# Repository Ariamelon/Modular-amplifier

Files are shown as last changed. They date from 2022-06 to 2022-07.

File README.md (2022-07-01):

# Modular amplifier
A PCB for a compact but complete headphone amplifier package. Designed to fit in [this](https://item.taobao.com/item.htm?id=629378026025) case.

## Key Features
* Swappable amplifier and relay attenuator modules
* Large heatsink with variable position based on thermal planes of amplifier modules
* +-13.7V voltage rails for the amplifier modules
* +5V secondary rail for the microcontroller, relays and logic
* Power on/off anti-thump functionality
* DC offset and overheat protection
* Differential/SE mode
* Mute mode
* Standby mode

An on-board ATtiny2313A-P is used to control these functions:
* 4-channel 256-step relay-based attenuator controlled via a standard pot
* RGB state indicator LED (because why not)

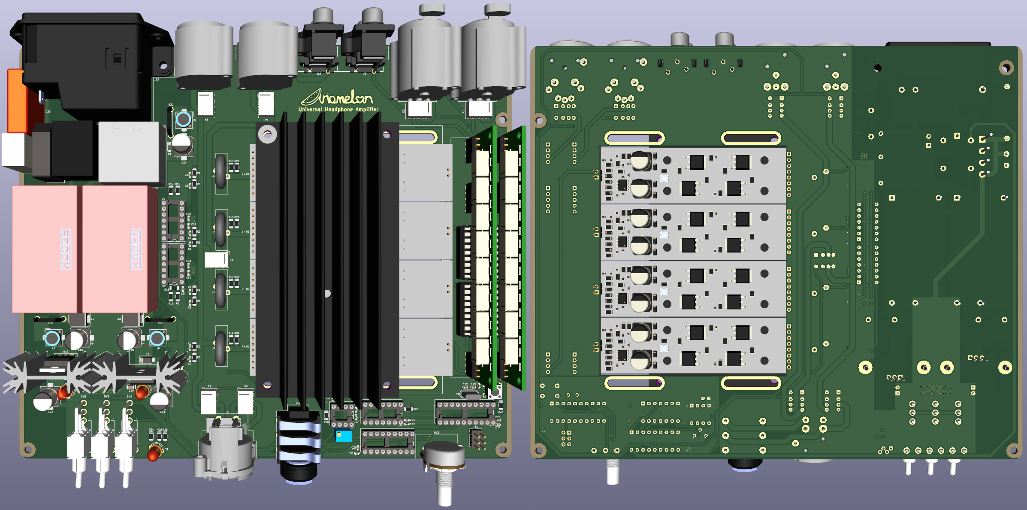
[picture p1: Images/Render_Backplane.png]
Render_Backplane

[PCB_Backplane](Images/Backplane-Assembly.pdf)
Schematic_Backplane

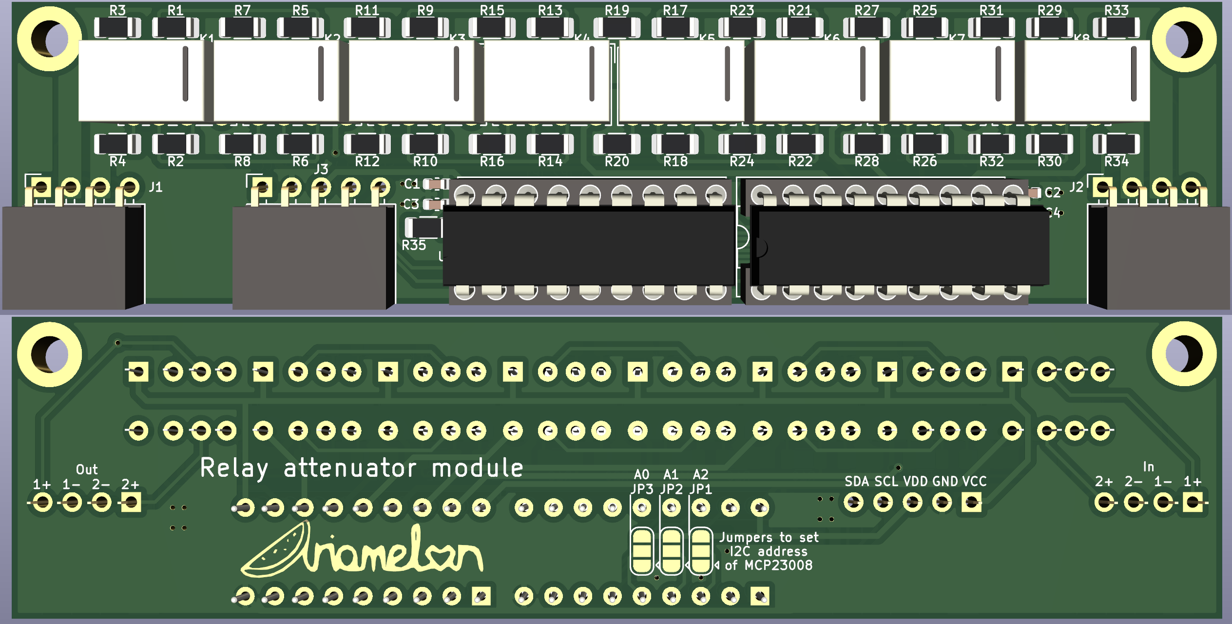
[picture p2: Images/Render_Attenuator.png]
Render_Attenuator

[PCB_Attenuator](Images/Attenuator-Assembly.pdf) 
Schematic_Attenuator

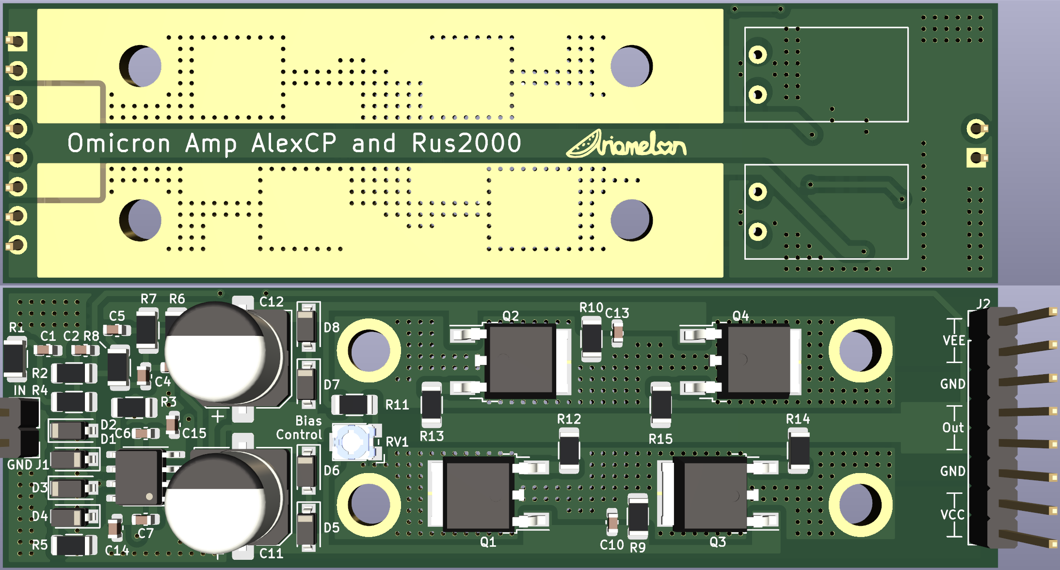
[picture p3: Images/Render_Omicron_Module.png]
Render_Omicron_Module

[PCB_Omicron_Module](Images/Omicron_Module-Assembly.pdf)
Schematic_Omicron_Module

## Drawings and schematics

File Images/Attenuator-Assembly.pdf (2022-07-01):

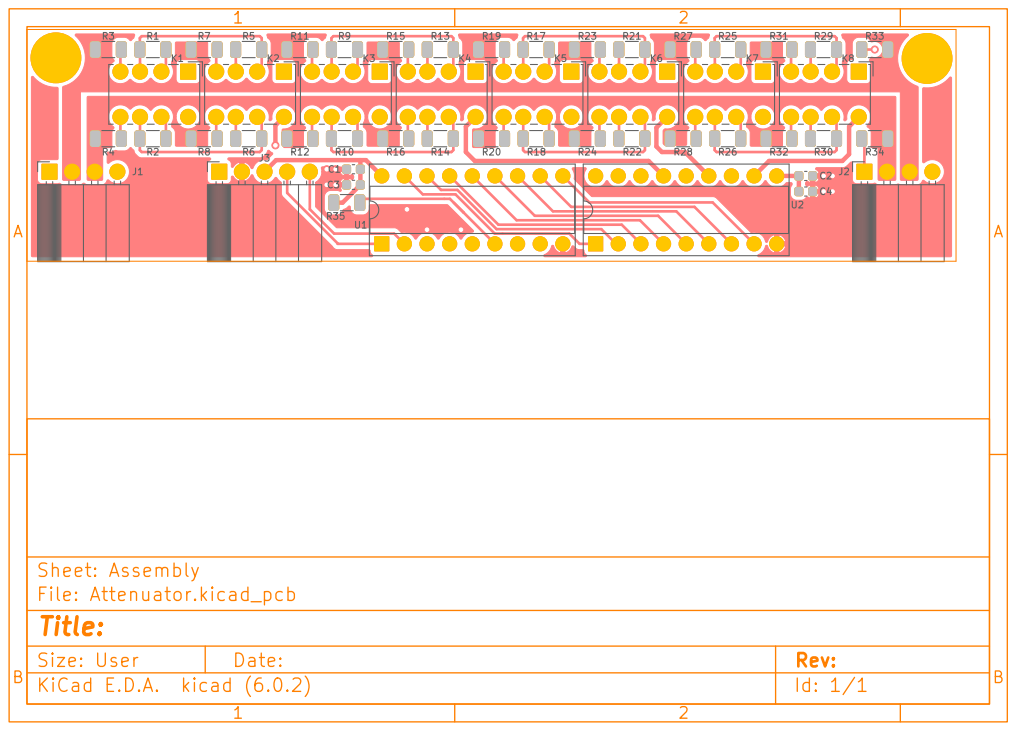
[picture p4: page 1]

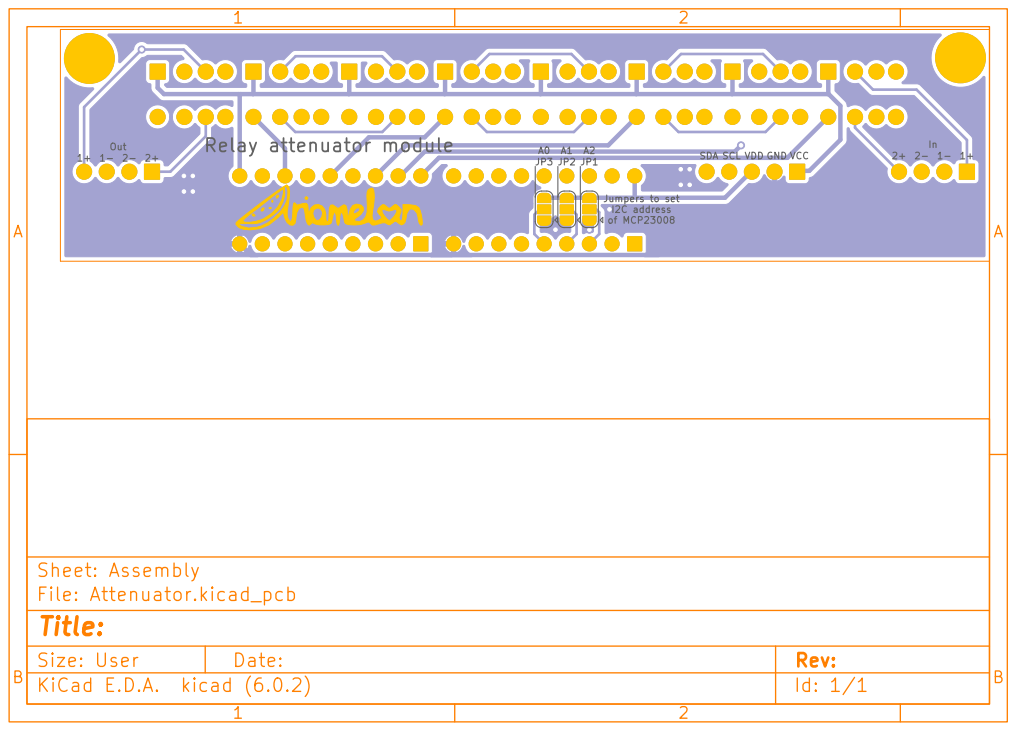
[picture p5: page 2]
In VDD; 2+ Out 1+; VCC A1; 1+ Relay attenuator module; SCL; GND; I2C address of MCP23008 A0; SDA; B Date: KiCad E.D.A. kicad (6.0.2) Size: User; Rev:; Id: 1/1 Title:; File: Attenuator.kicad_pcb; Sheet: Assembly

Jumpers to set

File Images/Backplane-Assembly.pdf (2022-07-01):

# U11 K²

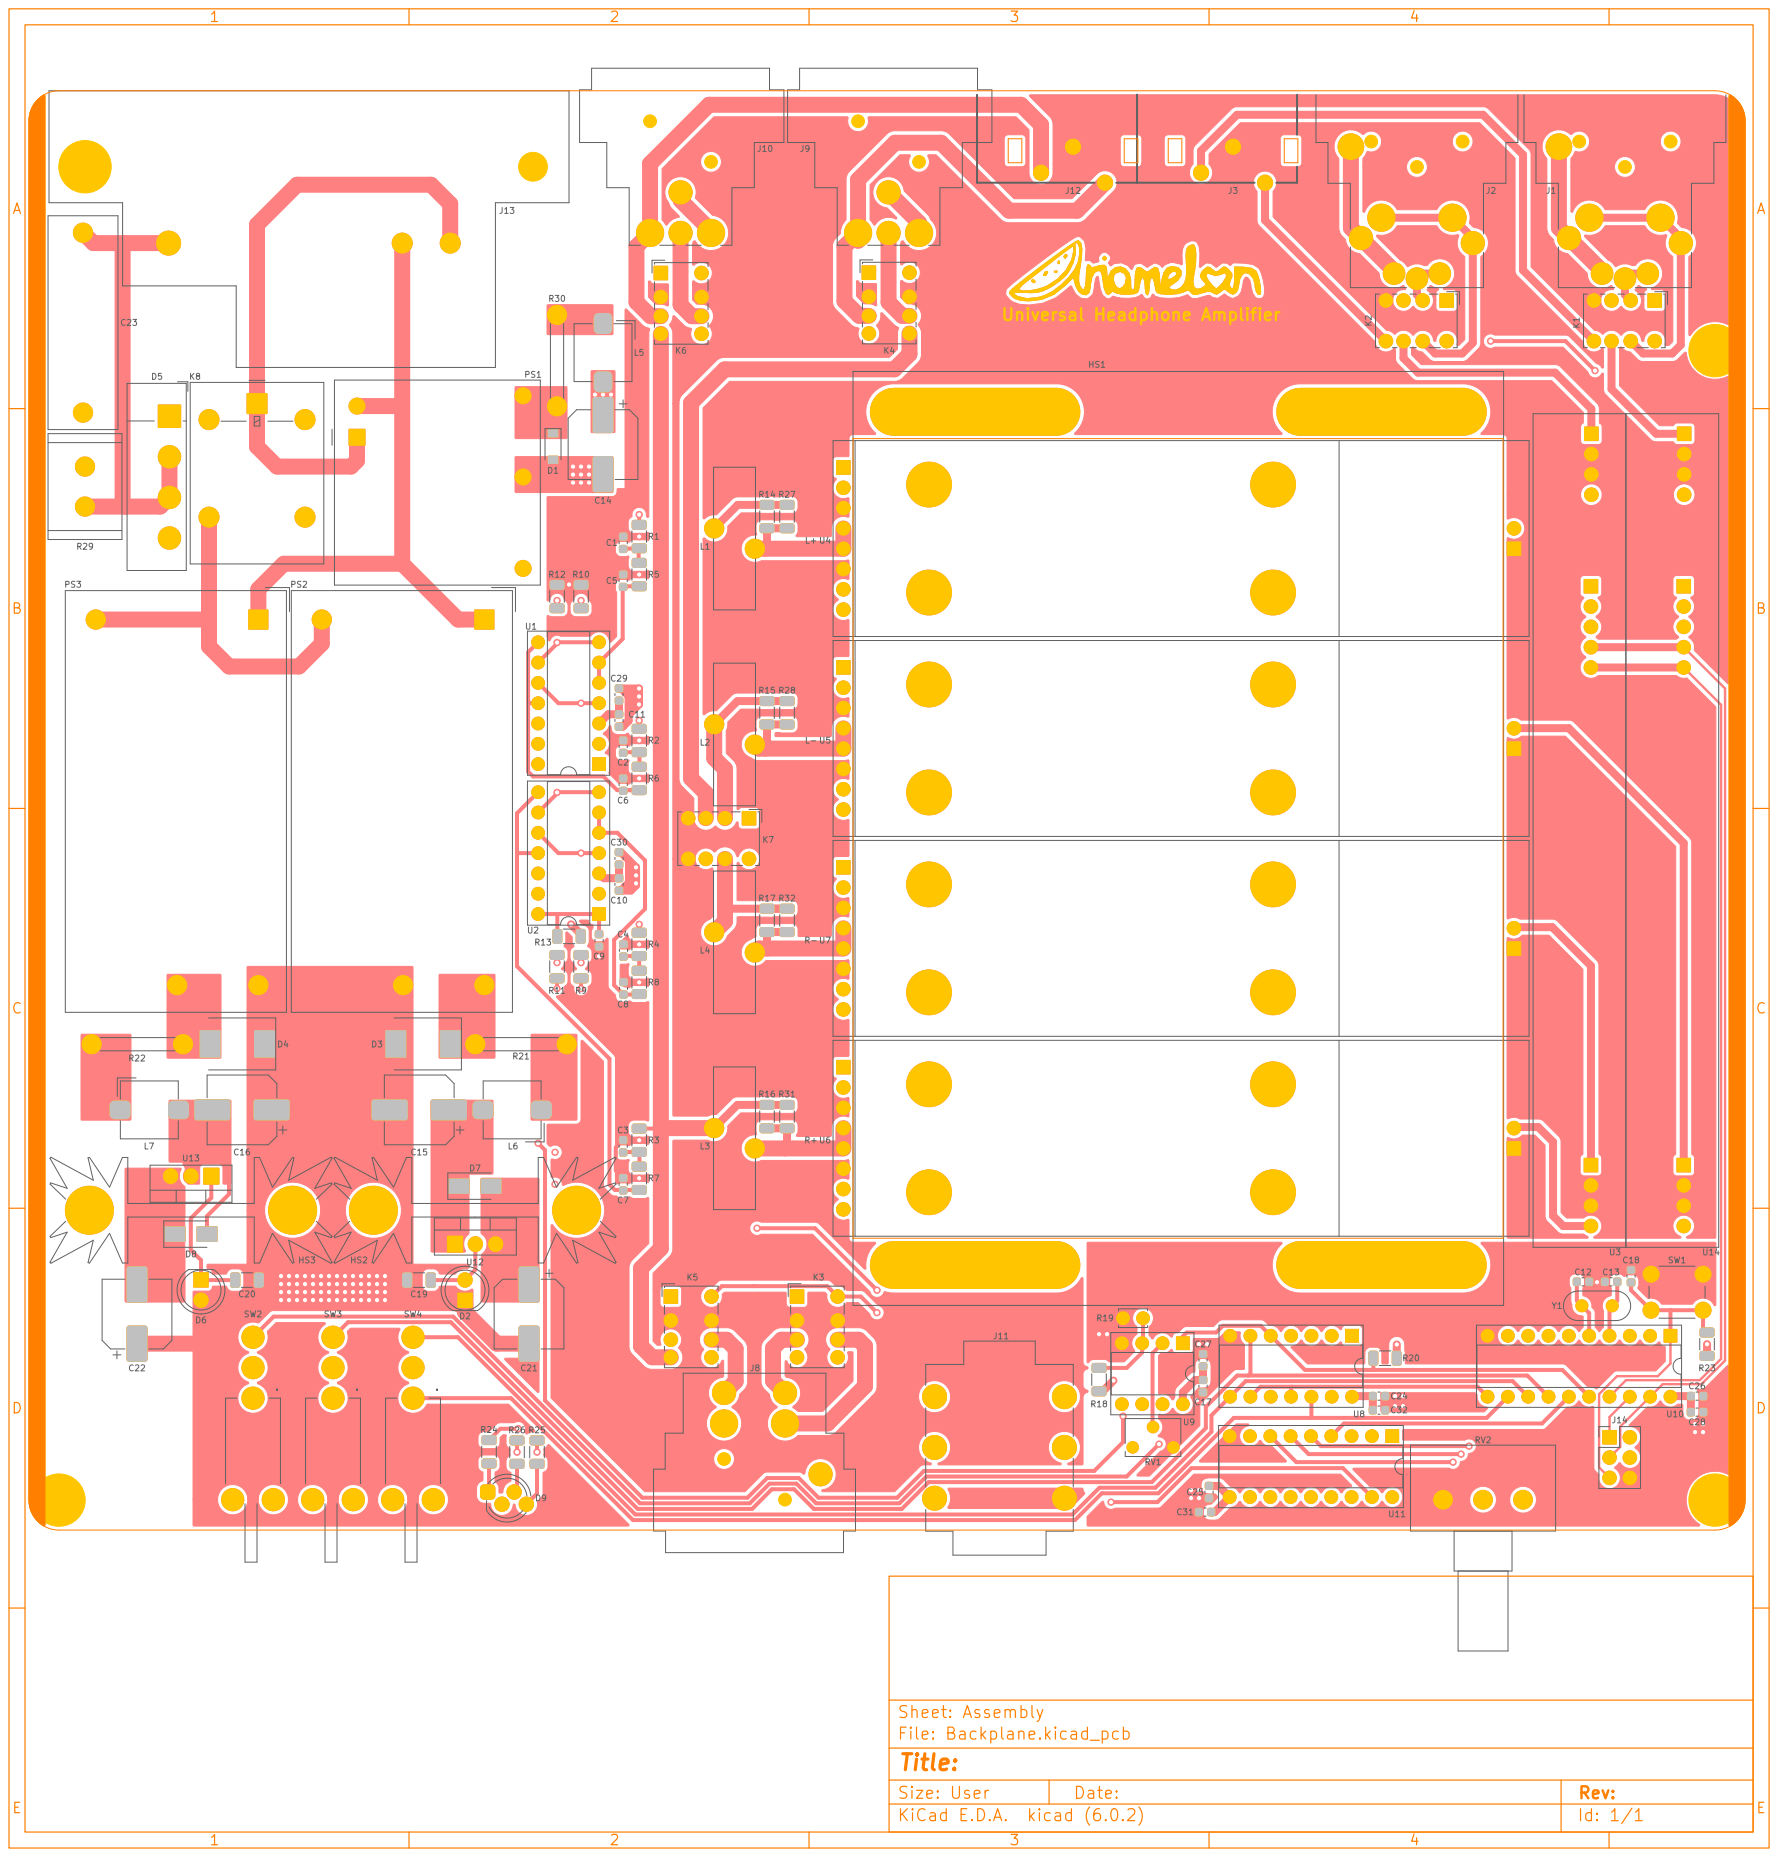
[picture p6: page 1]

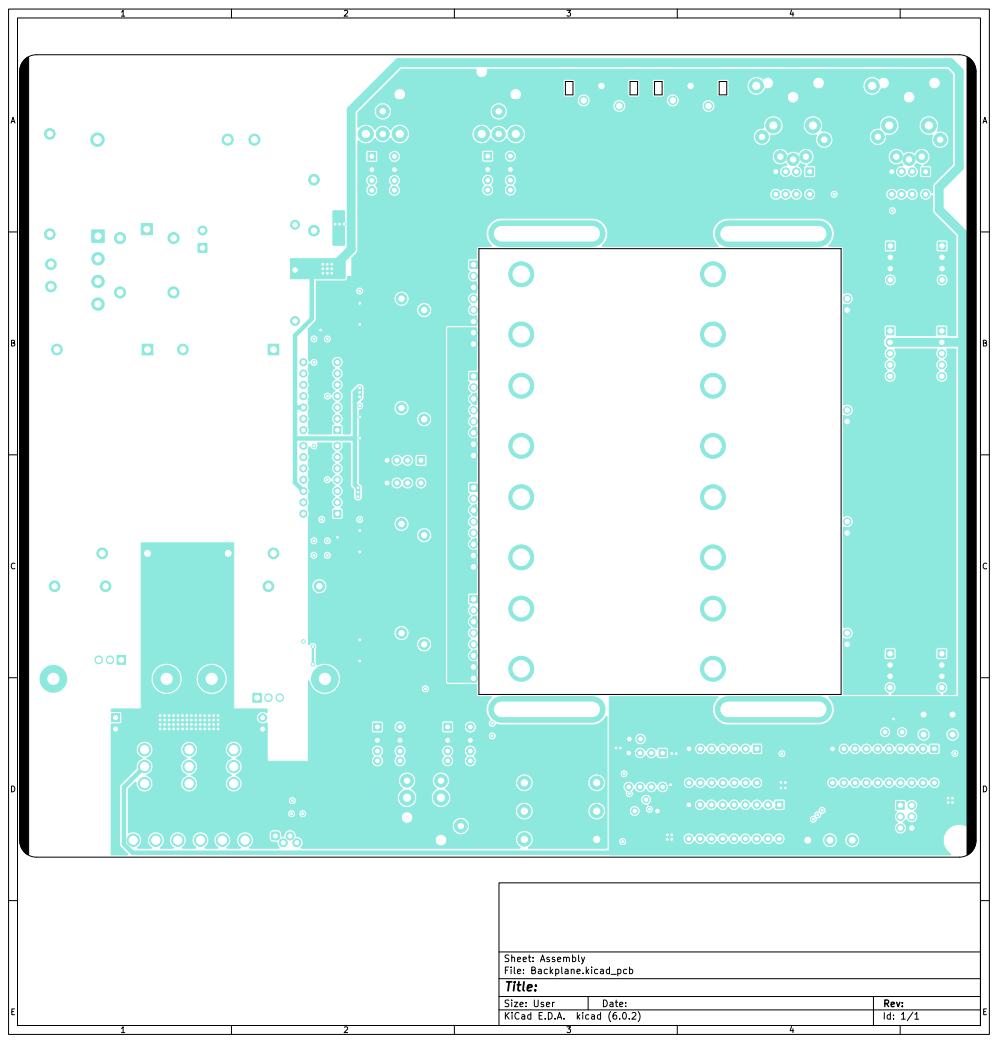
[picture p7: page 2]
File: Backplane.kicad_pcb; Sheet: Assembly

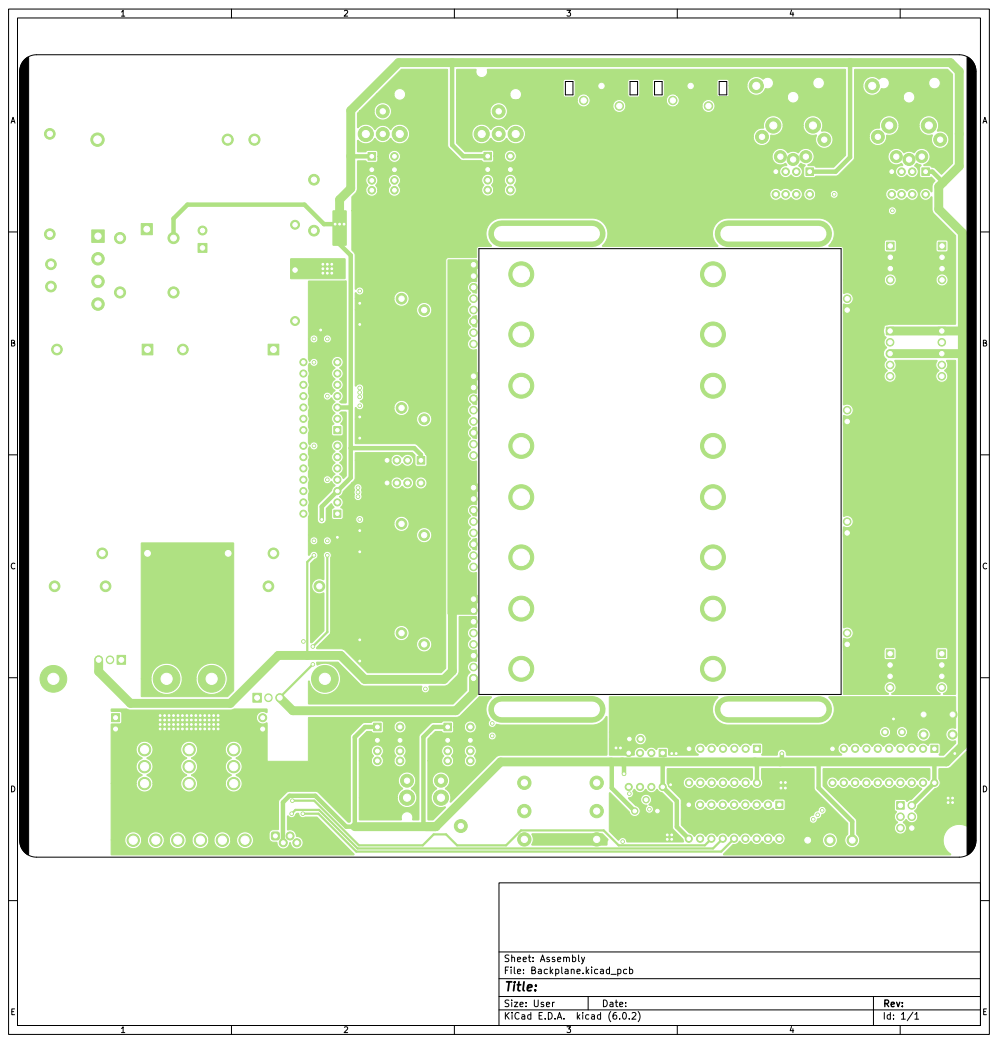
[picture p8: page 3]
File: Backplane.kicad_pcb; Sheet: Assembly

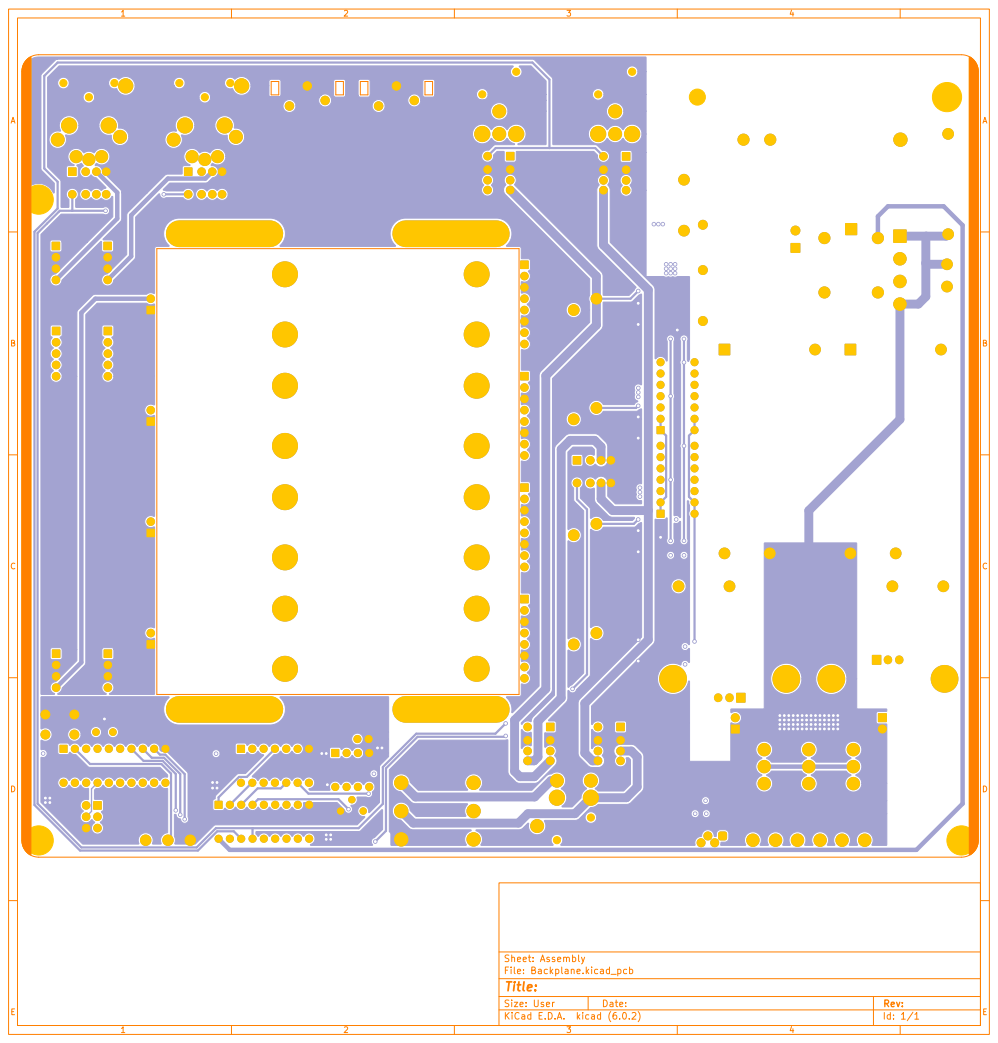
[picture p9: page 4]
File: Backplane.kicad_pcb; Sheet: Assembly

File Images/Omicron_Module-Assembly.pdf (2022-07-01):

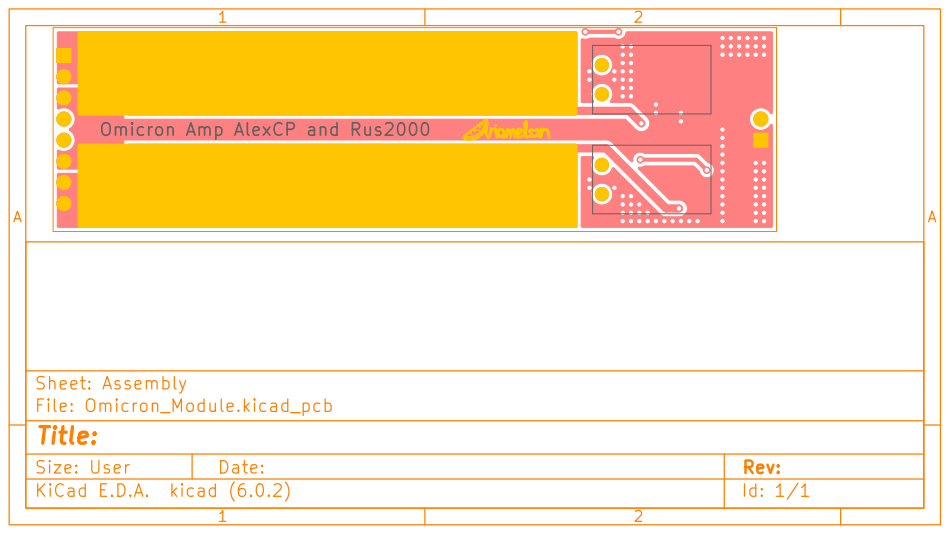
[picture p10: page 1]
A Date: KiCad E.D.A. kicad (6.0.2) Size: User; Rev:; Id: 1/1 Title:; File: Omicron_Module.kicad_pcb; Sheet: Assembly

Omicron Amp AlexCP and Rus2000

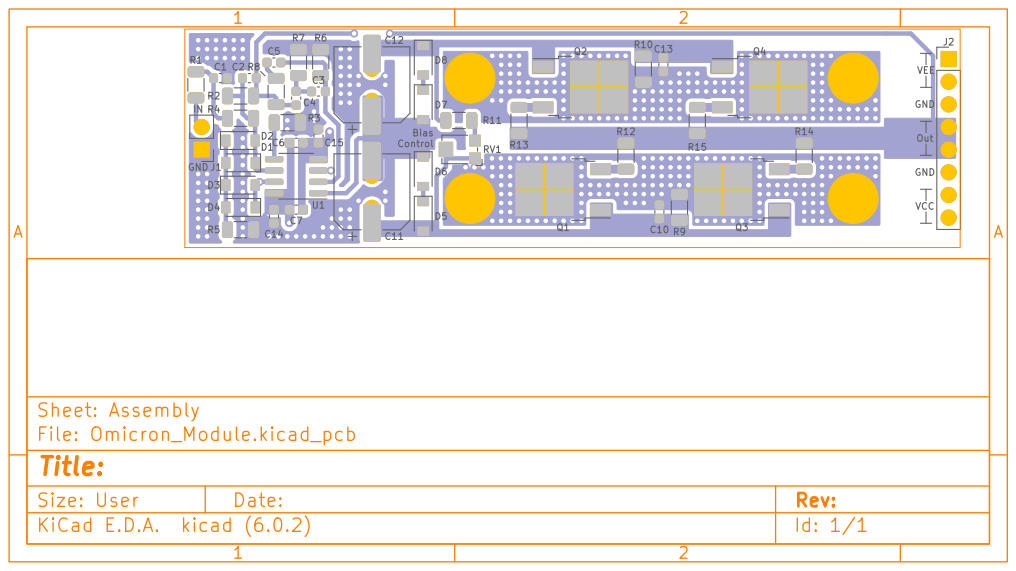
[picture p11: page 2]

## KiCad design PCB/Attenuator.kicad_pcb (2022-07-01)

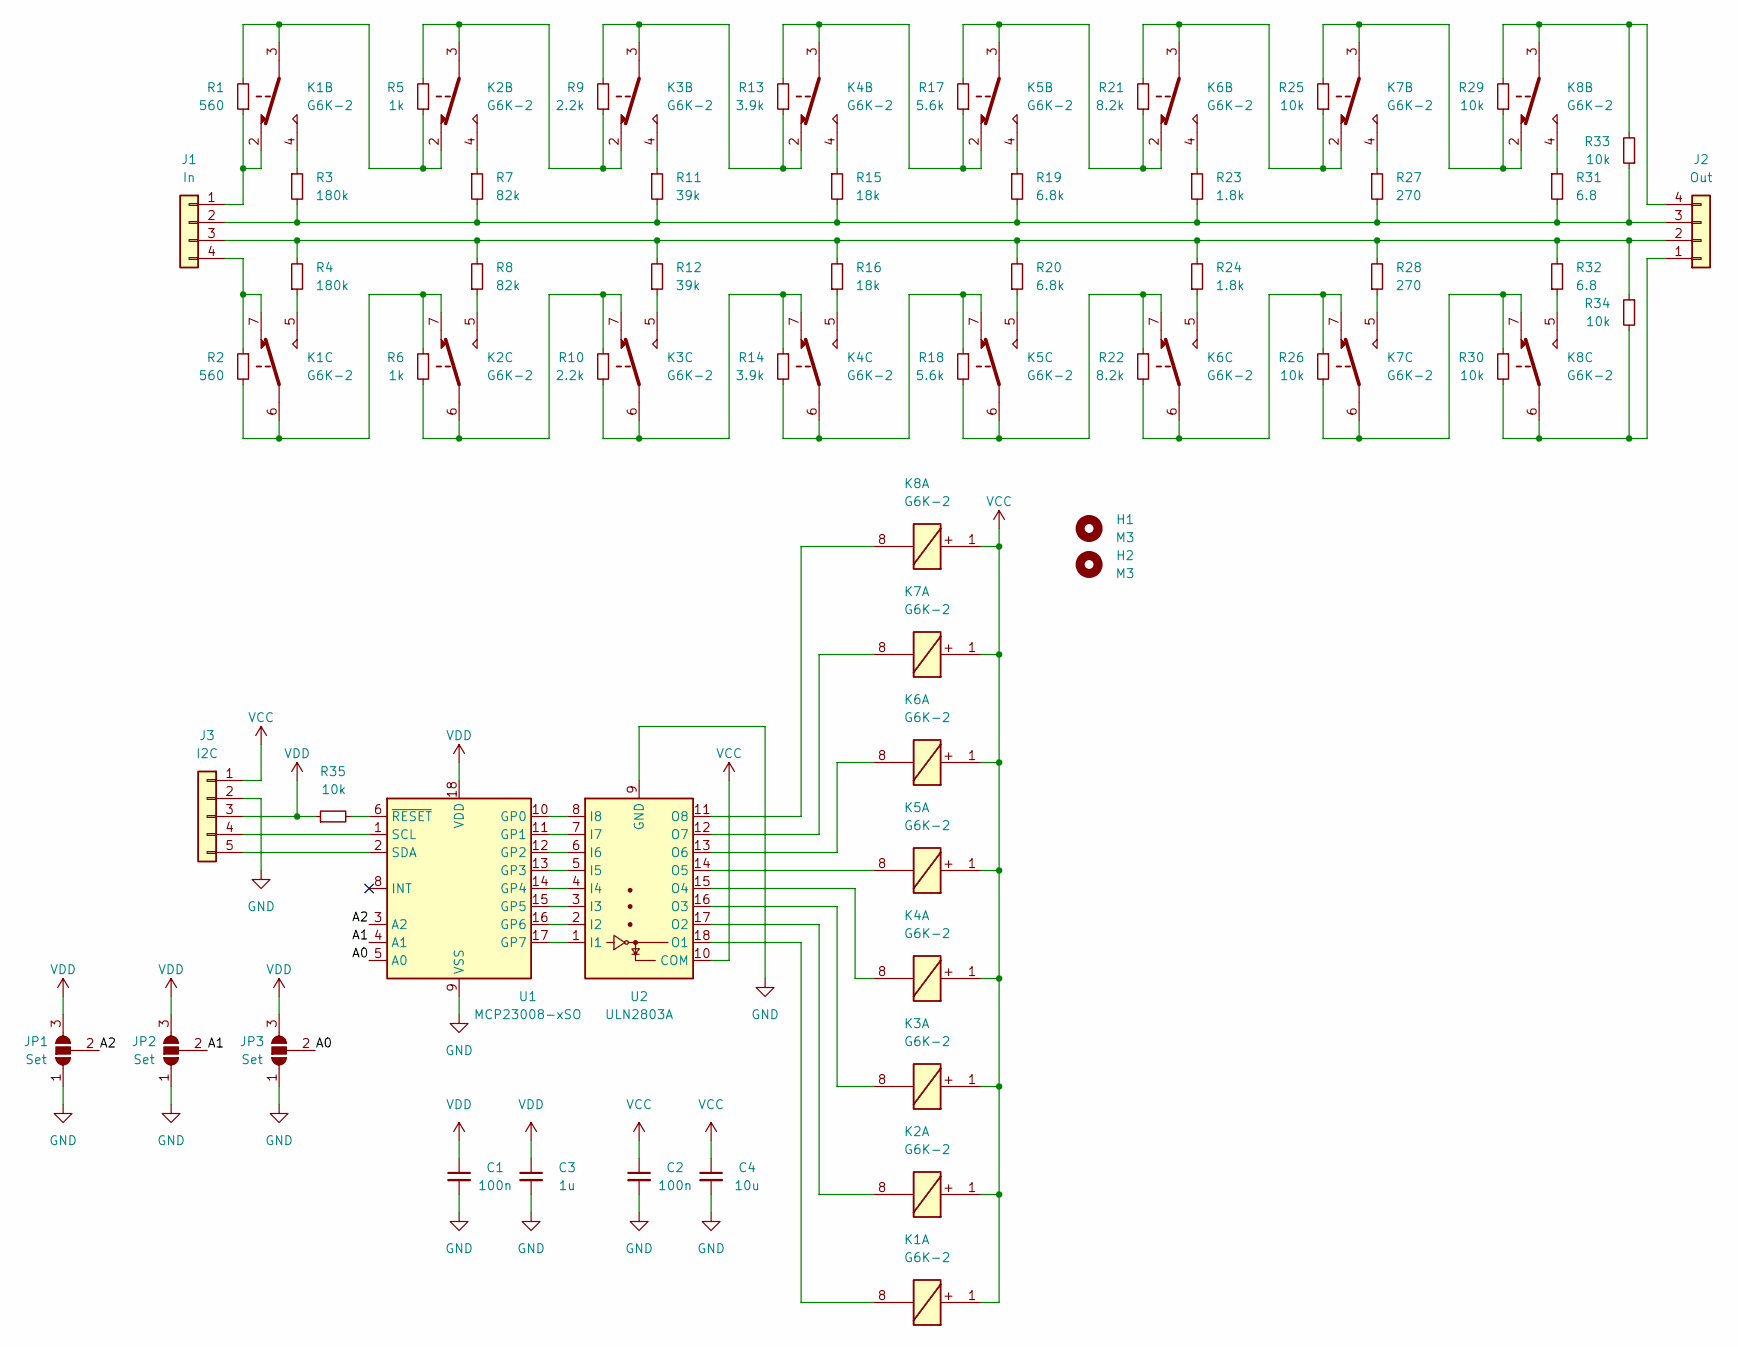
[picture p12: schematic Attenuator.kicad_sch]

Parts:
C1, C2: 100n; C_0603_1608Metric; Part number CL10A105KB8NNNC; LCSC part number C15849
C3: 1u; C_0603_1608Metric; Part number CL10A105KB8NNNC; LCSC part number C15849
C4: 10u; C_0603_1608Metric; Part number CL10A105KB8NNNC; LCSC part number C15849
H1, H2: M3; MountingHole_3.2mm_M3_DIN965_Pad
J1: In; PinSocket_1x04_P2.54mm_Horizontal
J2: Out; PinSocket_1x04_P2.54mm_Horizontal
J3: I2C; PinSocket_1x05_P2.54mm_Horizontal
JP1, JP2, JP3: Set; SolderJumper-3_P1.3mm_Open_RoundedPad1.0x1.5mm
K1, K2, K3, K4, K5, K6, K7, K8: G6K-2; Relay_DPDT_Omron_G6K-2P-Y
R1, R2: 560; R_1206_3216Metric
R3, R4: 180k; R_1206_3216Metric
R5, R6: 1k; R_1206_3216Metric
R7, R8: 82k; R_1206_3216Metric
R9, R10: 2.2k; R_1206_3216Metric
R11, R12: 39k; R_1206_3216Metric
R13, R14: 3.9k; R_1206_3216Metric
R15, R16: 18k; R_1206_3216Metric
R17, R18: 5.6k; R_1206_3216Metric
R19, R20: 6.8k; R_1206_3216Metric
R21, R22: 8.2k; R_1206_3216Metric
R23, R24: 1.8k; R_1206_3216Metric
R25, R26, R29, R30, R33, R34, R35: 10k; R_1206_3216Metric
R27, R28: 270; R_1206_3216Metric
R31, R32: 6.8; R_1206_3216Metric
U1: MCP23008-xSO; DIP-18_W7.62mm_Socket
U2: ULN2803A; DIP-18_W7.62mm_Socket

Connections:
/A0: JP3.2 (C), U1.5 (A0)
/A1: JP2.2 (C), U1.4 (A1)
/A2: JP1.2 (C), U1.3 (A2)
GND: C1.2, C2.2, C3.2, C4.2, J3.2, JP1.1 (A), JP2.1 (A), JP3.1 (A), U1.9 (VSS), U2.9 (GND)
unnamed: J1.1, K1.2, R1.1
unnamed: J1.2, J2.3, R3.2, R7.2, R11.2, R15.2, R19.2, R23.2, R27.2, R31.2, R33.1
unnamed: J1.3, J2.2, R4.2, R8.2, R12.2, R16.2, R20.2, R24.2, R28.2, R32.2, R34.1
unnamed: J1.4, K1.7, R2.1
unnamed: J2.1, K8.6, R30.2, R34.2
unnamed: J2.4, K8.3, R29.2, R33.2
unnamed: J3.4, U1.1 (SCL)
unnamed: J3.5, U1.2 (SDA)
unnamed: K1.3, K2.2, R1.2, R5.1
unnamed: K1.4, R3.1
unnamed: K1.5, R4.1
unnamed: K1.6, K2.7, R2.2, R6.1
unnamed: K1.8, U2.18 (O1)
unnamed: K2.3, K3.2, R5.2, R9.1
unnamed: K2.4, R7.1
unnamed: K2.5, R8.1
unnamed: K2.6, K3.7, R6.2, R10.1
unnamed: K2.8, U2.17 (O2)
unnamed: K3.3, K4.2, R9.2, R13.1
unnamed: K3.4, R11.1
unnamed: K3.5, R12.1
unnamed: K3.6, K4.7, R10.2, R14.1
unnamed: K3.8, U2.16 (O3)
unnamed: K4.3, K5.2, R13.2, R17.1
unnamed: K4.4, R15.1
unnamed: K4.5, R16.1
unnamed: K4.6, K5.7, R14.2, R18.1
unnamed: K4.8, U2.15 (O4)
unnamed: K5.3, K6.2, R17.2, R21.1
unnamed: K5.4, R19.1
unnamed: K5.5, R20.1
unnamed: K5.6, K6.7, R18.2, R22.1
unnamed: K5.8, U2.14 (O5)
unnamed: K6.3, K7.2, R21.2, R25.1
unnamed: K6.4, R23.1
unnamed: K6.5, R24.1
unnamed: K6.6, K7.7, R22.2, R26.1
unnamed: K6.8, U2.13 (O6)
unnamed: K7.3, K8.2, R25.2, R29.1
unnamed: K7.4, R27.1
unnamed: K7.5, R28.1
unnamed: K7.6, K8.7, R26.2, R30.1
unnamed: K7.8, U2.12 (O7)
unnamed: K8.4, R31.1
unnamed: K8.5, R32.1
unnamed: K8.8, U2.11 (O8)
unnamed: R35.2, U1.6 (~RESET)
unnamed: U1.10 (GP0), U2.8 (I8)
unnamed: U1.11 (GP1), U2.7 (I7)
unnamed: U1.12 (GP2), U2.6 (I6)
unnamed: U1.13 (GP3), U2.5 (I5)
unnamed: U1.14 (GP4), U2.4 (I4)
unnamed: U1.15 (GP5), U2.3 (I3)
unnamed: U1.16 (GP6), U2.2 (I2)
unnamed: U1.17 (GP7), U2.1 (I1)
VCC: C2.1, C4.1, J3.1, K1.1, K2.1, K3.1, K4.1, K5.1, K6.1, K7.1, K8.1, U2.10 (COM)
VDD: C1.1, C3.1, J3.3, JP1.3 (B), JP2.3 (B), JP3.3 (B), R35.1, U1.18 (VDD)

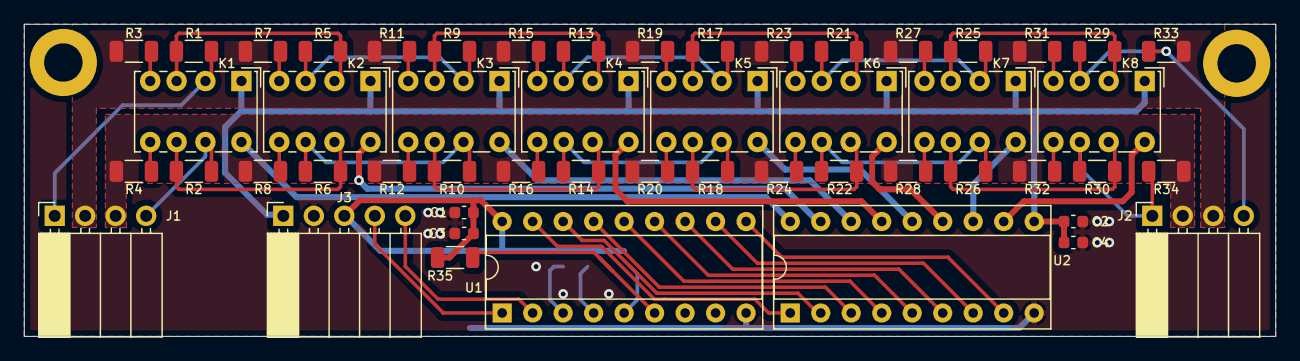
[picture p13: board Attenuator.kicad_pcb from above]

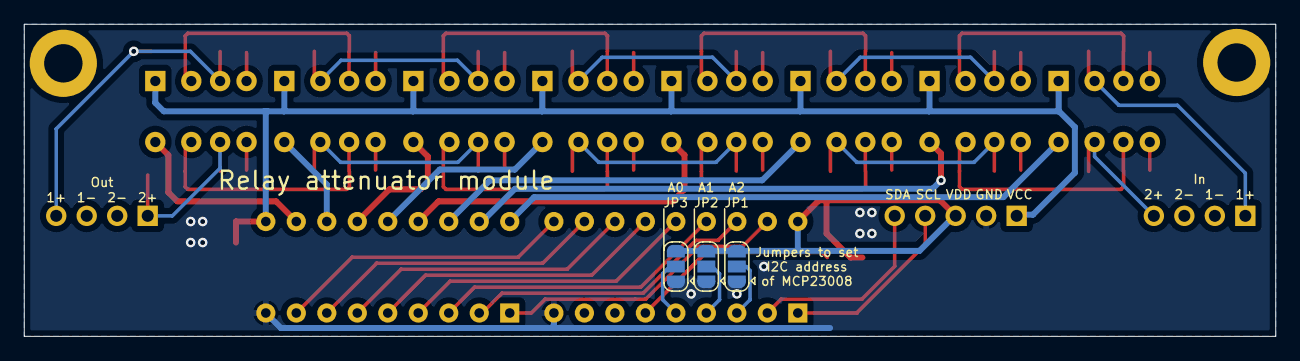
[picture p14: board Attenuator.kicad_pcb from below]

Board: 2 copper layers, 104.2 x 26.0 mm, 57 parts (3 on the bottom side), 61 nets.

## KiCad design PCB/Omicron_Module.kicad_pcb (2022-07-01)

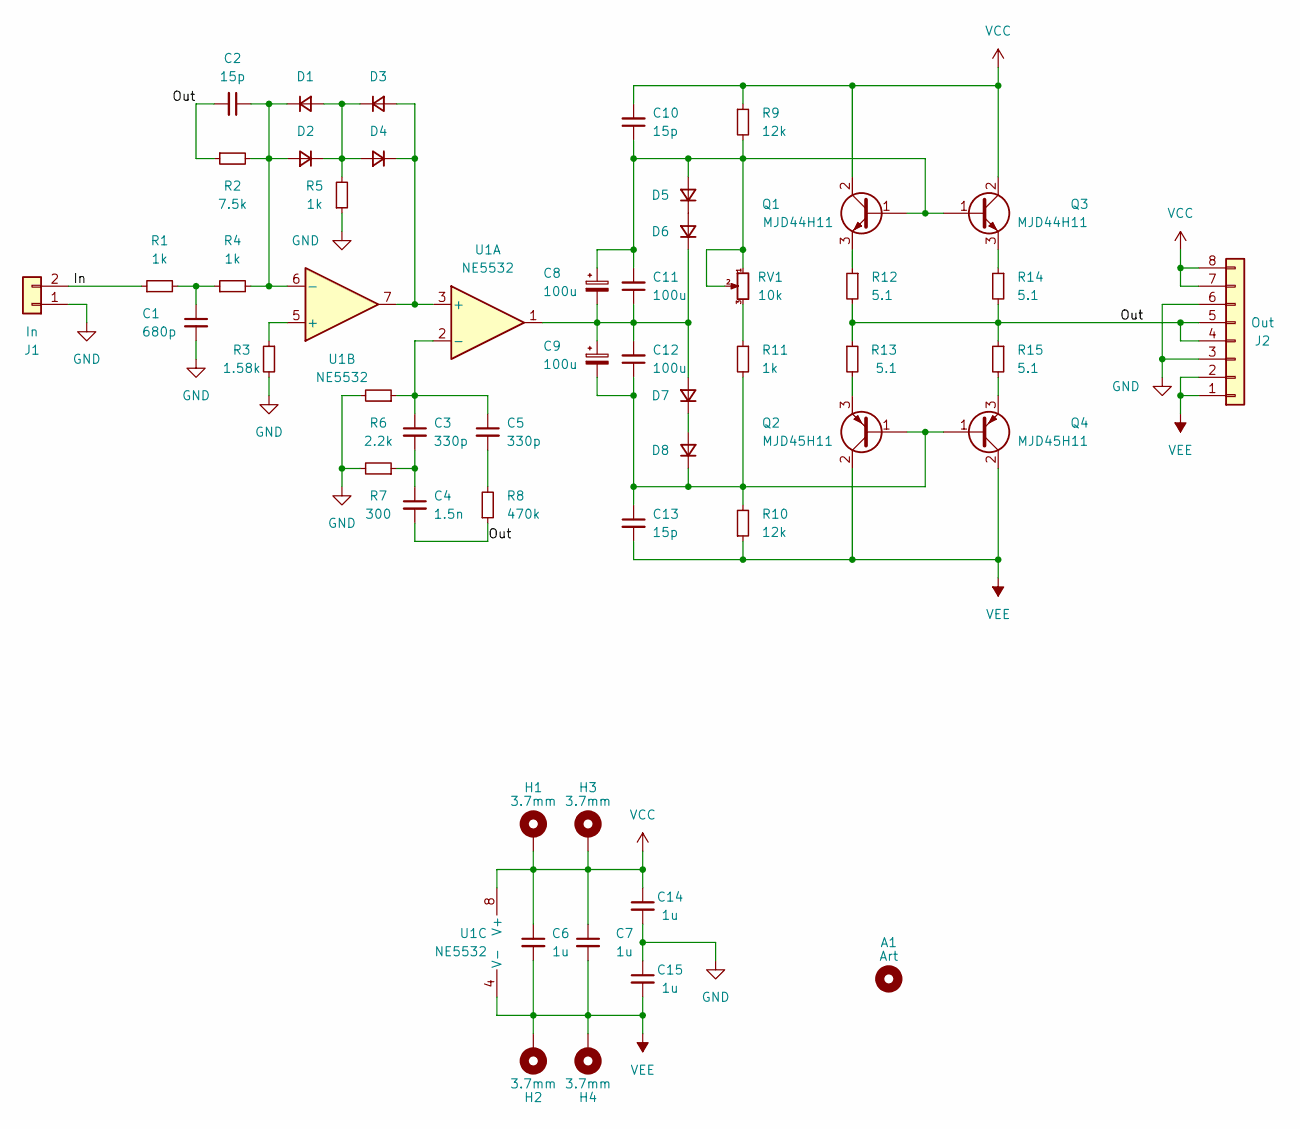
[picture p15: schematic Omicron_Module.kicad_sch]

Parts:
A1: Art; Ariamelon_Logo_CU
C1: 680p; C_0603_1608Metric
C2, C10, C13: 15p; C_0603_1608Metric
C3, C5: 330p; C_0603_1608Metric
C4: 1.5n; C_0603_1608Metric
C6, C7, C14, C15: 1u; C_0603_1608Metric; Part number CL10A105KB8NNNC; LCSC part number C15849
C8, C9: 100u; CP_Elec_8x6.9; Part number EEE-FK1V101GV
C11, C12: 100u; C_Radial_D8.0mm_H11.5mm_P3.50mm_Sideways; Part number EEE-FK1V101GV
D1, D2, D3, D4, D5, D6, D7, D8: D; D_SOD-123; Part number 1N4148W; LCSC part number C81598
H1, H2, H3, H4: 3.7mm; MountingHole_3.2mm_M3_DIN965_Pad_3.7mm_Hole
J1: In; PinHeader_1x02_P2.54mm_Vertical
J2: Out; PinHeader_1x08_P2.54mm_Vertical
Q1, Q3: MJD44H11; TO-252-2
Q2, Q4: MJD45H11; TO-252-2
R1, R4, R5, R11: 1k; R_1206_3216Metric
R2: 7.5k; R_1206_3216Metric
R3: 1.58k; R_1206_3216Metric
R6: 2.2k; R_1206_3216Metric
R7: 300; R_1206_3216Metric
R8: 470k; R_1206_3216Metric
R9, R10: 12k; R_1206_3216Metric
R12, R13, R14, R15: 5.1; R_1206_3216Metric
RV1: 10k; Potentiometer_Bourns_TC33X_Vertical
U1: NE5532; SOIC-8_3.9x4.9mm_P1.27mm

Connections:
/In: J1.2, R1.1
/Out: C2.2, C4.2, J2.4, J2.5, R2.1, R8.1, R12.2, R13.1, R14.2, R15.1
GND: C1.2, C14.2, C15.1, J1.1, J2.3, J2.6, R3.2, R5.1, R6.2, R7.2
unnamed: C1.1, R1.2, R4.1
unnamed: C2.1, D1.1 (K), D2.2 (A), R2.2, R4.2, U1.6 (-)
unnamed: C3.1, C5.1, R6.1, U1.2 (-)
unnamed: C3.2, C4.1, R7.1
unnamed: C5.2, R8.2
unnamed: C8.1, C10.1, C11.2, D5.2 (A), Q1.1 (B), Q3.1 (B), R9.2, RV1.1, RV1.2
unnamed: C8.2, C9.1, C11.1, C12.2, D6.1 (K), D7.2 (A), U1.1
unnamed: C9.2, C12.1, C13.1, D8.1 (K), Q2.1 (B), Q4.1 (B), R10.2, R11.2
unnamed: D1.2 (A), D2.1 (K), D3.1 (K), D4.2 (A), R5.2
unnamed: D3.2 (A), D4.1 (K), U1.3 (+), U1.7
unnamed: D5.1 (K), D6.2 (A)
unnamed: D7.1 (K), D8.2 (A)
unnamed: Q1.3 (E), R12.1
unnamed: Q2.3 (E), R13.2
unnamed: Q3.3 (E), R14.1
unnamed: Q4.3 (E), R15.2
unnamed: R3.1, U1.5 (+)
unnamed: R11.1, RV1.3
VCC: C6.1, C7.1, C10.2, C14.1, H1.1, H3.1, J2.7, J2.8, Q1.2 (C), Q3.2 (C), R9.1, U1.8 (V+)
VEE: C6.2, C7.2, C13.2, C15.2, H2.1, H4.1, J2.1, J2.2, Q2.2 (C), Q4.2 (C), R10.1, U1.4 (V-)

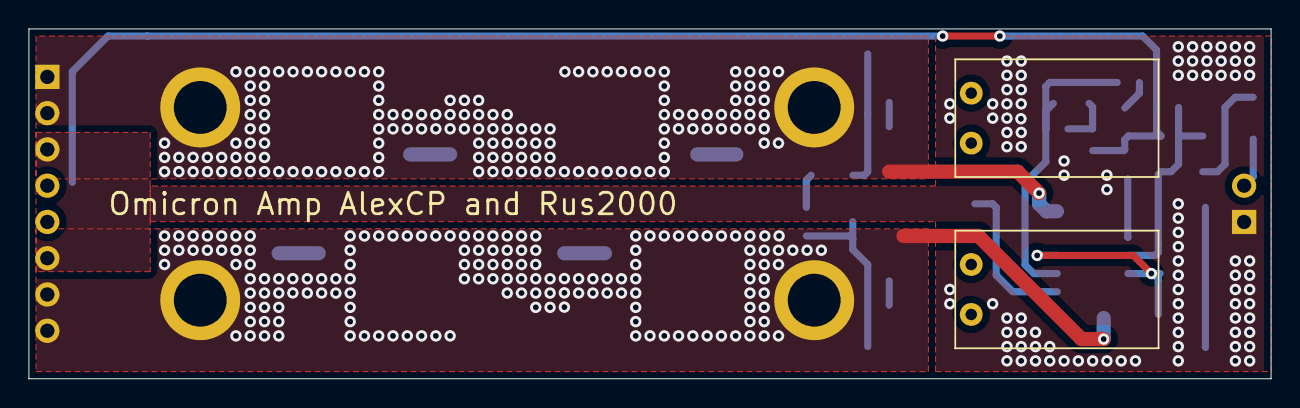
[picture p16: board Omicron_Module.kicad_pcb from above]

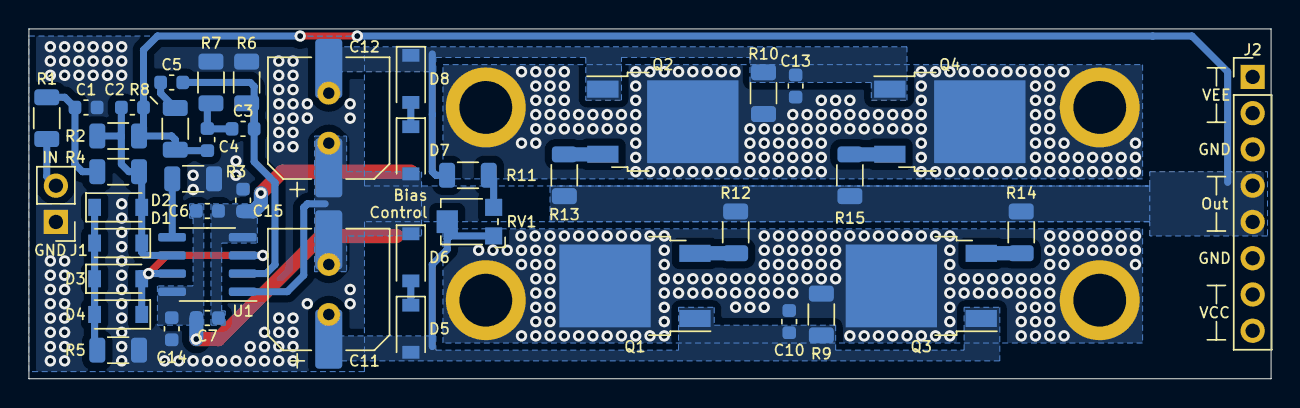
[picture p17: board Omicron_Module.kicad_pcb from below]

Board: 2 copper layers, 87.0 x 24.5 mm, 51 parts (48 on the bottom side), 23 nets.

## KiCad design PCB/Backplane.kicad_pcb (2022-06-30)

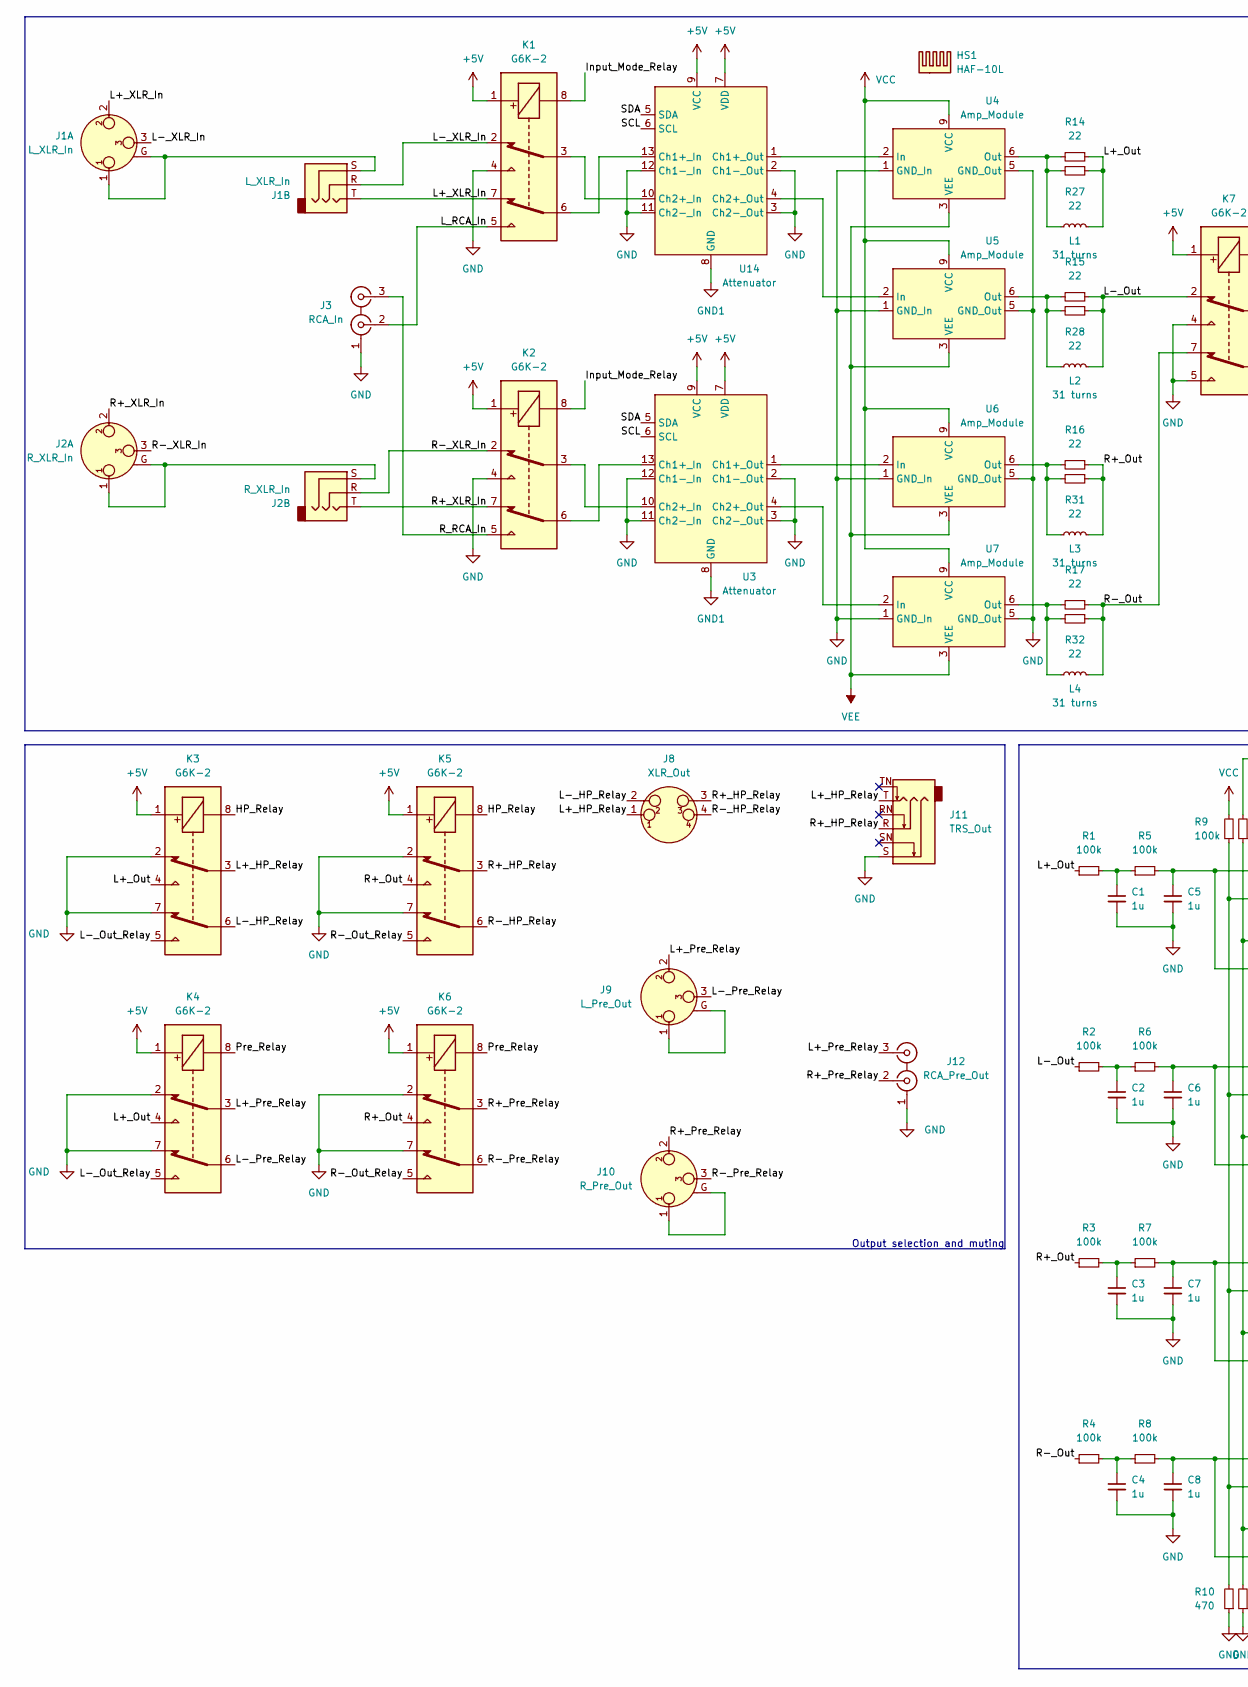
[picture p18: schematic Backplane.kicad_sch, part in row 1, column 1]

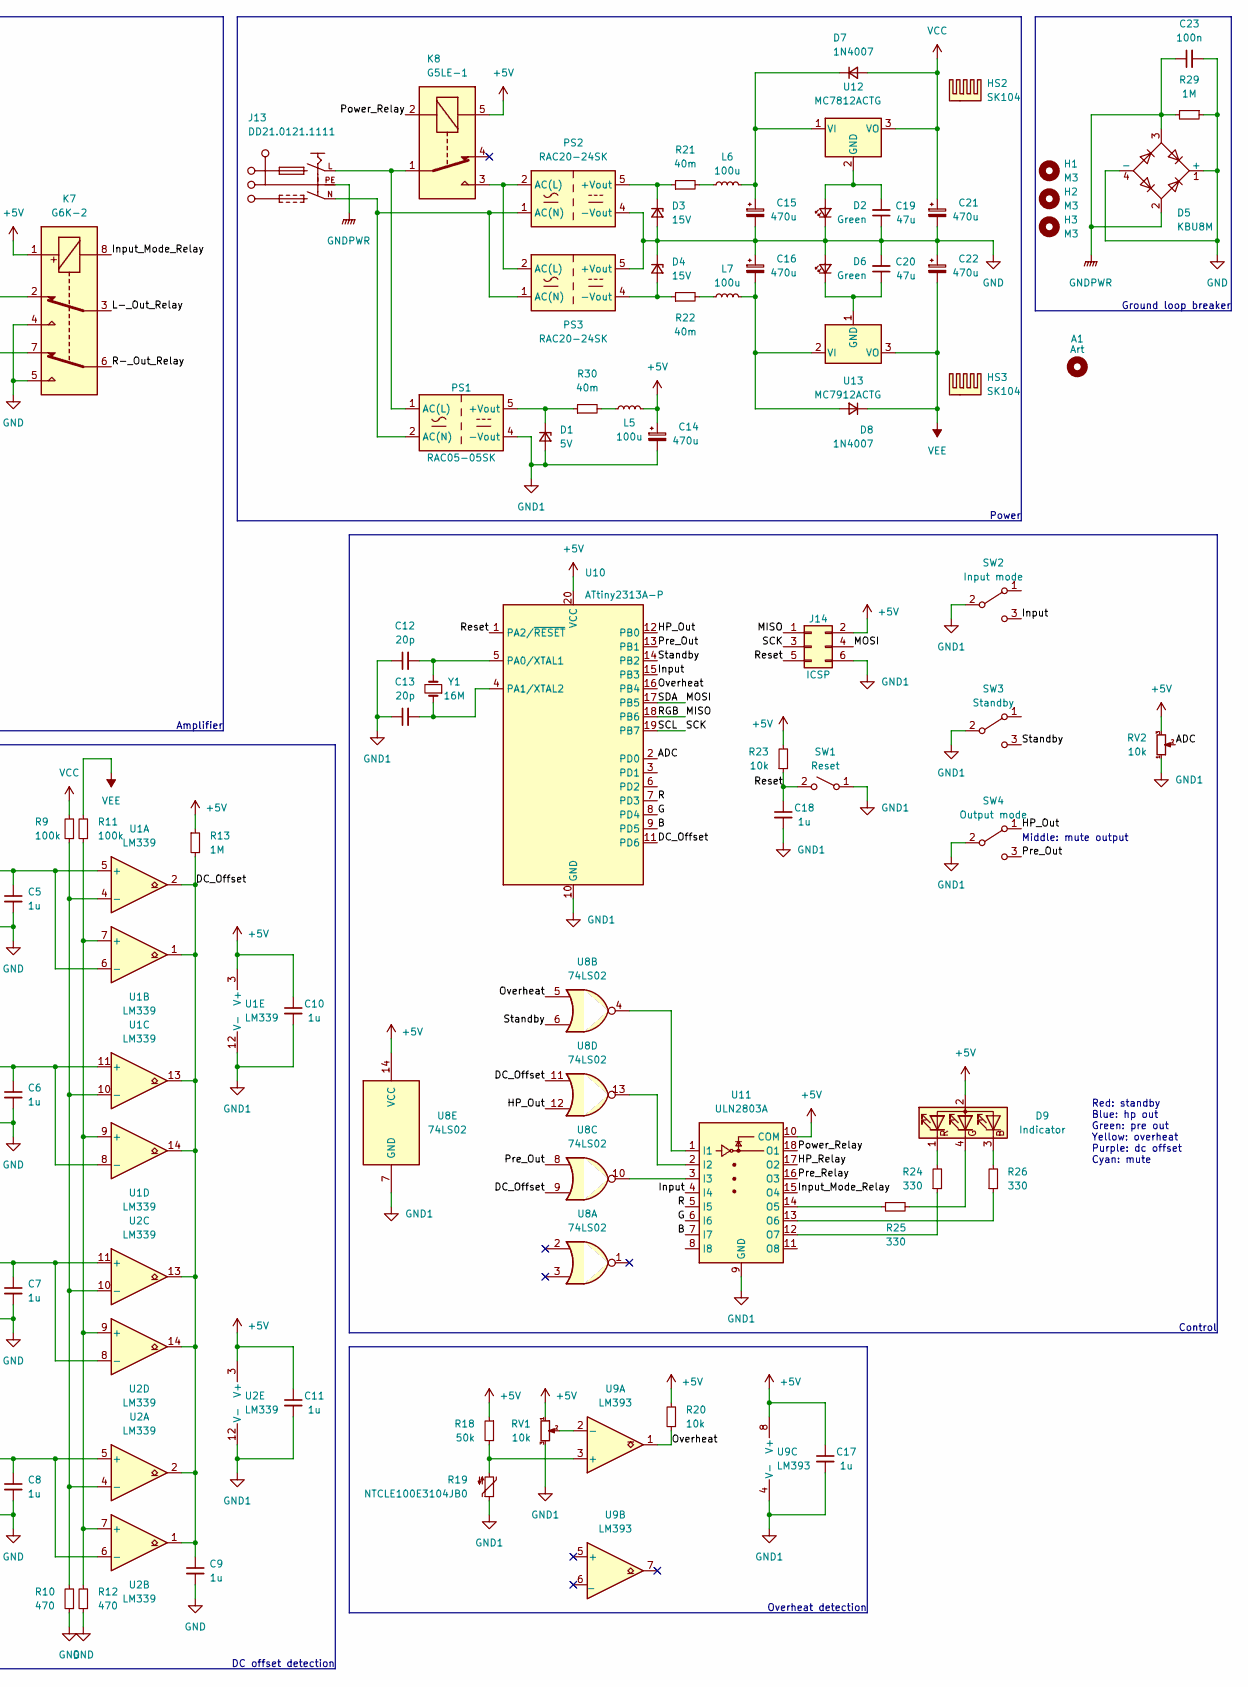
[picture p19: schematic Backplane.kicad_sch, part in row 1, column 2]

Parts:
A1: Art; Ariamelon_Logo_x3_CU
C1, C2, C3, C4, C5, C6, C7, C8: 1u; C_0603_1608Metric
C9, C10, C11, C17, C18: 1u; C_0603_1608Metric; Part number CL10A105KB8NNNC; LCSC part number C15849
C12, C13: 20p; C_0603_1608Metric
C14, C15, C16, C21, C22: 470u; CP_Elec_8x10.5; Part number EEEFT1E471GP; LCSC part number C193277
C19, C20: 47u; C_1206_3216Metric
C23: 100n; C_Rect_L26.5mm_W8.5mm_P22.50mm_MKS4; Part number PHE820ED6100MR06L2; LCSC part number C2926846
D1: 5V; D_SOD-123; LCSC part number C193402
D2, D6: Green; LED_D5.0mm
D3, D4: 15V; D_SMC; Part number SMCJ15CA-13-F
D5: KBU8M; Diode_Bridge_Vishay_KBU
D7, D8: 1N4007; D_SMA
D9: Indicator; LED_D5.0mm-4_RGB_Staggered_Pins
H1, H2, H3: M3; MountingHole_3.2mm_M3
HS1: HAF-10L
HS2, HS3: SK104; Heatsink_Fischer_SK104-STC-STIC_35x13mm_2xDrill2.5mm
J1: L_XLR_In; Jack_XLR-6.35mm_Neutrik_NCJ6FA-H_Horizontal
J2: R_XLR_In; Jack_XLR-6.35mm_Neutrik_NCJ6FA-H_Horizontal
J3: RCA_In; RCJ-2221
J8: XLR_Out; Jack_XLR_Neutrik_NC4FAH_Horizontal
J9: L_Pre_Out; Jack_XLR_Neutrik_NC3MAH_Horizontal
J10: R_Pre_Out; Jack_XLR_Neutrik_NC3MAH_Horizontal
J11: TRS_Out; Jack_6.35mm_Neutrik_NMJ6HCD2_Horizontal
J12: RCA_Pre_Out; RCJ-2221
J13: DD21.0121.1111; SCHURTER_DD21.0121.1111
J14: ICSP; PinHeader_2x03_P2.54mm_Vertical
K1, K2, K3, K4, K5, K6, K7: G6K-2; Relay_DPDT_Omron_G6K-2P-Y
K8: G5LE-1; Relay_SPDT_Omron-G5LE-1
L1, L2, L3, L4: 31 turns; L_Toroid_D15mm_W4mm; Part number N/A; LCSC part number N/A
L5, L6, L7: 100u; L_TDK_SLF7032; Part number SPM7054VT-101M-D; LCSC part number C2045491
PS1: RAC05-05SK; Converter_ACDC_RECOM_RAC05-xxSK_THT
PS2, PS3: RAC20-24SK; Converter_ACDC_Recom_RAC20-xxSK_THT
R1, R2, R3, R4, R5, R6, R7, R8, R9, R11: 100k; R_1206_3216Metric; Part number RT1206FRD0710KL; LCSC part number C705072
R10, R12: 470; R_1206_3216Metric; Part number RT1206FRD0710KL; LCSC part number C705072
R13: 1M; R_1206_3216Metric; Part number RT1206FRE071ML; LCSC part number C375528
R14, R15, R16, R17, R27, R28, R31, R32: 22; R_1206_3216Metric; Part number RT1206FRD073RL; LCSC part number C326707
R18: 50k; R_1206_3216Metric; Part number RT1206FRD0710KL; LCSC part number C705072
R19: NTCLE100E3104JB0; C_Disc_D3.4mm_W2.1mm_P2.50mm
R20, R23: 10k; R_1206_3216Metric; Part number RT1206FRD0710KL; LCSC part number C705072
R21, R22, R30: 40m; OAR1; Part number RT1206BRD074R99L; LCSC part number C326584
R24, R25, R26: 330; R_1206_3216Metric; Part number RT1206FRD0710KL; LCSC part number C705072
R29: 1M; R_Radial_Power_L13.0mm_W9.0mm_P5.00mm; Part number RT1206FRE071ML; LCSC part number C375528
RV1: 10k; Potentiometer_Bourns_3266W_Vertical
RV2: 10k; Potentiometer_Alps_RK163_Single_Horizontal
SW1: Reset; SW_PUSH_6mm
SW2: Input mode; 100SP1T2B4M7RE; Part number 100SP1T2B4M7RE
SW3: Standby; 100SP1T2B4M7RE; Part number 100SP1T2B4M7RE
SW4: Output mode; 100SP1T2B4M7RE; Part number 100SP1T2B4M7RE
U1, U2: LM339; DIP-14_W7.62mm_Socket
U3, U14: Attenuator
U4, U5, U6, U7: Amp_Module
U8: 74LS02; DIP-14_W7.62mm_Socket
U9: LM393; DIP-8_W7.62mm_Socket
U10: ATtiny2313A-P; DIP-20_W7.62mm_Socket
U11: ULN2803A; DIP-18_W7.62mm_Socket
U12: MC7812ACTG; TO-220-3_Vertical
U13: MC7912ACTG; TO-220-3_Vertical
Y1: 16M; Crystal_HC52-6mm_Vertical

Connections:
+5V: C10.1, C11.1, C14.1, C17.1, D9.2 (A), J14.2, K1.1, K2.1, K3.1, K4.1, K5.1, K6.1, K7.1, K8.5, L5.2, R13.1, R18.1, R20.2, R23.2, RV1.1, RV2.3, U1.3 (V+), U2.3 (V+), U3.7 (VDD), U3.9 (VCC), U8.14 (VCC), U9.8 (V+), U10.20 (VCC), U11.10 (COM), U14.7 (VDD), U14.9 (VCC)
/ADC: RV2.2, U10.2 (PD0)
/B: U10.9 (PD5), U11.7 (I7)
/DC_Offset: C9.1, R13.2, U1.1, U1.2, U1.13, U1.14, U2.1, U2.2, U2.13, U2.14, U8.9, U8.11, U10.11 (PD6)
/G: U10.8 (PD4), U11.6 (I6)
/HP_Out: SW4.1 (A), U8.12, U10.12 (PB0)
/HP_Relay: K3.8, K5.8, U11.17 (O2)
/Input: SW2.3 (C), U10.15 (PB3), U11.4 (I4)
/Input_Mode_Relay: K1.8, K2.8, K7.8, U11.15 (O4)
/L+_HP_Relay: J8.1, J11.T, K3.3
/L+_Out: K3.4, K4.4, L1.2, R1.1, R14.1, R27.1
/L+_Pre_Relay: J9.2, J12.3 (IN1), K4.3
/L+_XLR_In: J1.2, J1.T, K1.7
/L-_HP_Relay: J8.2, K3.6
/L-_Out: K7.2, L2.2, R2.1, R15.1, R28.1
/L-_Out_Relay: K3.5, K4.5, K7.3
/L-_Pre_Relay: J9.3, K4.6
/L-_XLR_In: J1.3, J1.R, K1.2
/L_RCA_In: J3.2 (IN2), K1.5
/MISO: J14.1, U10.18 (PB6)
/MOSI: J14.4, U3.5 (SDA), U10.17 (PB5), U14.5 (SDA)
/Overheat: R20.1, U8.5, U9.1, U10.16 (PB4)
/Power_Relay: K8.2, U11.18 (O1)
/Pre_Out: SW4.3 (C), U8.8, U10.13 (PB1)
/Pre_Relay: K4.8, K6.8, U11.16 (O3)
/R: U10.7 (PD3), U11.5 (I5)
/R+_HP_Relay: J8.3, J11.R, K5.3
/R+_Out: K5.4, K6.4, L3.2, R3.1, R16.1, R31.1
/R+_Pre_Relay: J10.2, J12.2 (IN2), K6.3
/R+_XLR_In: J2.2, J2.T, K2.7
/R-_HP_Relay: J8.4, K5.6
/R-_Out: K7.7, L4.2, R4.1, R17.1, R32.1
/R-_Out_Relay: K5.5, K6.5, K7.6
/R-_Pre_Relay: J10.3, K6.6
/R-_XLR_In: J2.3, J2.R, K2.2
/R_RCA_In: J3.3 (IN1), K2.5
/Reset: C18.1, J14.5, R23.1, SW1.2 (B), U10.1 (PA2/~RESET)
/SCK: J14.3, U3.6 (SCL), U10.19 (PB7), U14.6 (SCL)
/Standby: SW3.3 (C), U8.6, U10.14 (PB2)
GND: C1.2, C2.2, C3.2, C4.2, C5.2, C6.2, C7.2, C8.2, C9.2, C15.2, C16.1, C19.1, C20.2, C21.2, C22.1, C23.2, D2.1 (K), D3.2 (A), D4.1 (K), D5.1 (+), D5.4 (-), D6.2 (A), J3.1 (EXT), J11.S, J12.1 (EXT), K1.4, K2.4, K3.2, K3.7, K4.2, K4.7, K5.2, K5.7, K6.2, K6.7, K7.4, K7.5, PS2.4 (-Vout), PS3.5 (+Vout), R10.1, R12.1, R29.1, U3.2 (Ch1-_Out), U3.3 (Ch2-_Out), U3.11 (Ch2-_In), U3.12 (Ch1-_In), U4.1 (GND_In), U4.5 (GND_Out), U4.8 (GND_Out), U5.1 (GND_In), U5.5 (GND_Out), U5.8 (GND_Out), U6.1 (GND_In), U6.5 (GND_Out), U6.8 (GND_Out), U7.1 (GND_In), U7.5 (GND_Out), U7.8 (GND_Out), U14.2 (Ch1-_Out), U14.3 (Ch2-_Out), U14.11 (Ch2-_In), U14.12 (Ch1-_In)
GND1: C10.2, C11.2, C12.1, C13.1, C14.2, C17.2, C18.2, D1.2 (A), J14.6, PS1.4 (-Vout), R19.1, RV1.3, RV2.1, SW1.1 (A), SW2.2 (B), SW3.2 (B), SW4.2 (B), U1.12 (V-), U2.12 (V-), U3.8 (GND), U8.7 (GND), U9.4 (V-), U10.10 (GND), U11.9 (GND), U14.8 (GND)
GNDPWR: C23.1, D5.2, D5.3, J13.PE, R29.2
unnamed: C1.1, R1.2, R5.1
unnamed: C2.1, R2.2, R6.1
unnamed: C3.1, R3.2, R7.1
unnamed: C4.1, R4.2, R8.1
unnamed: C5.1, R5.2, U1.5 (+), U1.6 (-)
unnamed: C6.1, R6.2, U1.8 (-), U1.11 (+)
unnamed: C7.1, R7.2, U2.8 (-), U2.11 (+)
unnamed: C8.1, R8.2, U2.5 (+), U2.6 (-)
unnamed: C12.2, U10.5 (PA0/XTAL1), Y1.2
unnamed: C13.2, U10.4 (PA1/XTAL2), Y1.1
unnamed: C15.1, D7.1 (K), L6.2, U12.1 (VI)
unnamed: C16.2, D8.2 (A), L7.2, U13.2 (VI)
unnamed: C19.2, D2.2 (A), U12.2 (GND)
unnamed: C20.1, D6.1 (K), U13.1 (GND)
unnamed: D1.1 (K), PS1.5 (+Vout), R30.1
unnamed: D3.1 (K), PS2.5 (+Vout), R21.1
unnamed: D4.2 (A), PS3.4 (-Vout), R22.1
unnamed: D9.1 (RK), R24.2
unnamed: D9.3 (BK), R26.2
unnamed: D9.4 (GK), R25.2
unnamed: J1.1, J1.G, J1.S
unnamed: J2.1, J2.G, J2.S
unnamed: J9.1, J9.G
unnamed: J10.1, J10.G
unnamed: J13.L, K8.1, PS1.1 (AC(L))
unnamed: J13.N, PS1.2 (AC(N)), PS2.1 (AC(N)), PS3.1 (AC(N))
unnamed: K1.3, U14.10 (Ch2+_In)
unnamed: K1.6, U14.13 (Ch1+_In)
unnamed: K2.3, U3.10 (Ch2+_In)
unnamed: K2.6, U3.13 (Ch1+_In)
unnamed: K8.3, PS2.2 (AC(L)), PS3.2 (AC(L))
unnamed: L1.1, R14.2, R27.2, U4.6 (Out), U4.7 (Out)
unnamed: L2.1, R15.2, R28.2, U5.6 (Out), U5.7 (Out)
unnamed: L3.1, R16.2, R31.2, U6.6 (Out), U6.7 (Out)
unnamed: L4.1, R17.2, R32.2, U7.6 (Out), U7.7 (Out)
unnamed: L5.1, R30.2
unnamed: L6.1, R21.2
unnamed: L7.1, R22.2
unnamed: R9.1, R10.2, U1.4 (-), U1.10 (-), U2.4 (-), U2.10 (-)
unnamed: R11.1, R12.2, U1.7 (+), U1.9 (+), U2.7 (+), U2.9 (+)
unnamed: R18.2, R19.2, U9.3 (+)
unnamed: R24.1, U11.12 (O7)
unnamed: R25.1, U11.14 (O5)
unnamed: R26.1, U11.13 (O6)
unnamed: RV1.2, U9.2 (-)
unnamed: U3.1 (Ch1+_Out), U6.2 (In)
unnamed: U3.4 (Ch2+_Out), U7.2 (In)
unnamed: U8.4, U11.1 (I1)
unnamed: U8.13, U11.2 (I2)
unnamed: U8.10, U11.3 (I3)
unnamed: U4.2 (In), U14.1 (Ch1+_Out)
unnamed: U5.2 (In), U14.4 (Ch2+_Out)
VCC: C21.1, D7.2 (A), R9.2, U4.9 (VCC), U4.10 (VCC), U5.9 (VCC), U5.10 (VCC), U6.9 (VCC), U6.10 (VCC), U7.9 (VCC), U7.10 (VCC), U12.3 (VO)
VEE: C22.2, D8.1 (K), R11.2, U4.3 (VEE), U4.4 (VEE), U5.3 (VEE), U5.4 (VEE), U6.3 (VEE), U6.4 (VEE), U7.3 (VEE), U7.4 (VEE), U13.3 (VO)

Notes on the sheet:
Power
Red: standby Blue: hp out Green: pre out Yellow: overheat Purple: dc offset Cyan: mute
Overheat detection
Control
Amplifier
DC offset detection
Output selection and muting
Ground loop breaker
Middle: mute output

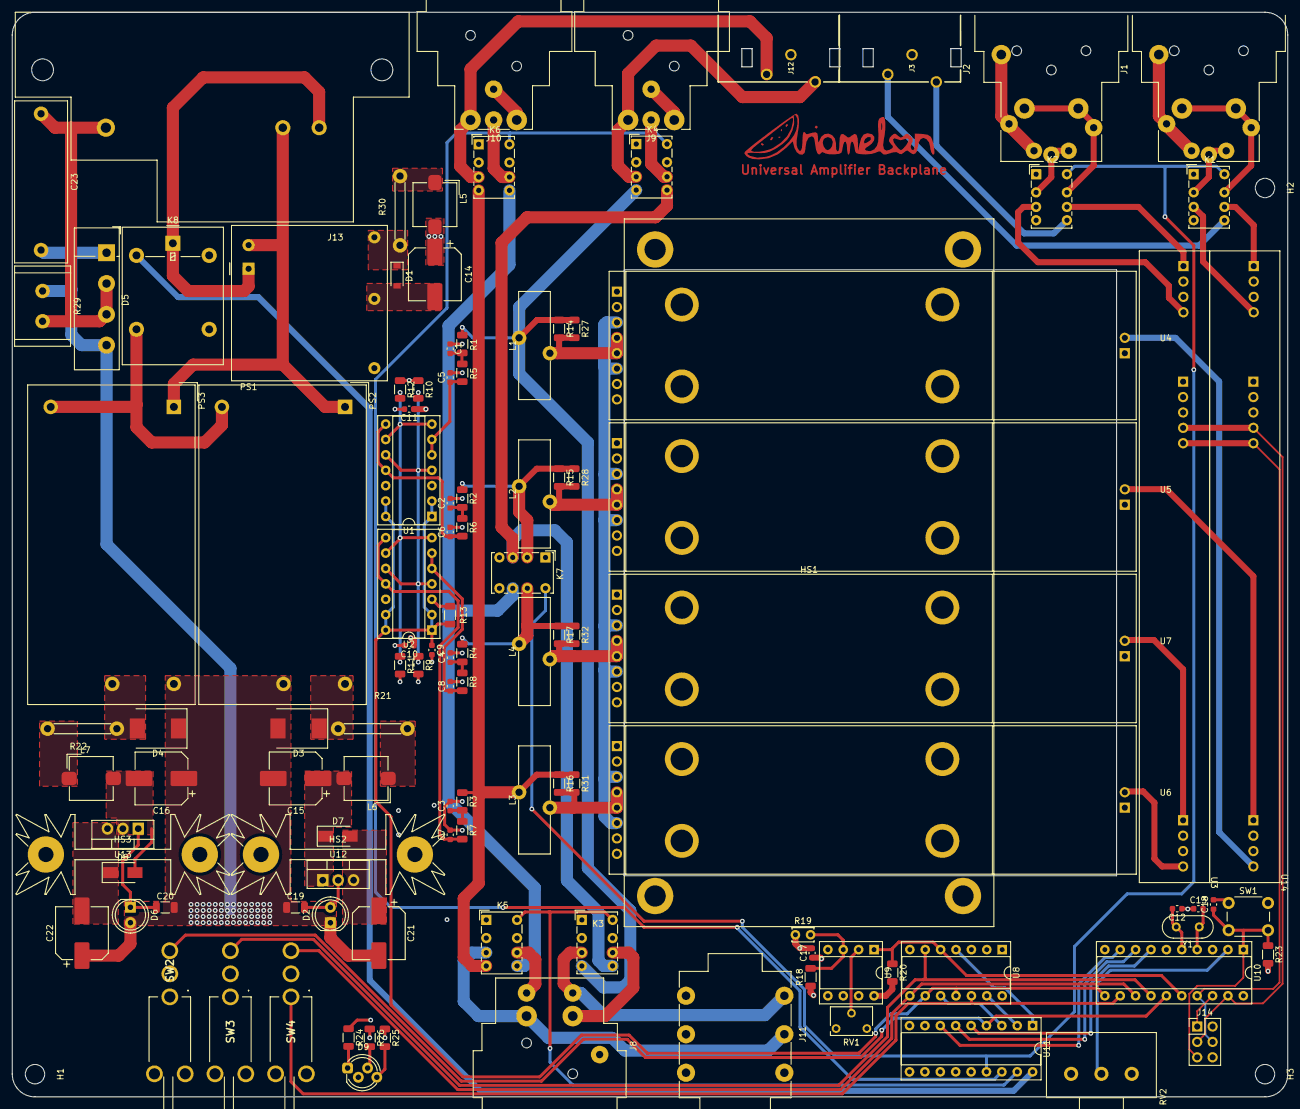
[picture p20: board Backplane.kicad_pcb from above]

Board: 4 copper layers, 210.5 x 179.0 mm, 120 parts (0 on the bottom side), 96 nets.

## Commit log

2022-06-30 Updated resistor values
    [Omicron_Module.kicad_sch]
2022-06-30 Added images, fixed gerbers, fixed attenuator silk
    [Attenuator.kicad_pcb, Backplane.kicad_sch, Omicron_Module.kicad_pcb]
2022-06-30 Updated silk, created heatsink rails to allow moving of heatsink position
2022-07-01 Uploaded more legible PDF files of the copper layers
    [Attenuator.kicad_pcb, Omicron_Module.kicad_pcb]
2022-07-01 Added 1u decoupling capacitors to ICs on backplane and attenuator boards
    [Attenuator.kicad_pcb, Attenuator.kicad_sch, Backplane.kicad_sch]
2022-07-01 Added bulk capacitance to each IC, rerouted 5V line on backplane board
    [Attenuator.kicad_pcb, Attenuator.kicad_sch, Backplane.kicad_sch]
